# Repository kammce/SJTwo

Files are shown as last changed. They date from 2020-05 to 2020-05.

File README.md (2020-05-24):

# SJTwo

Open source development board for the LPC4078 microcontroller with buttons,
leds, sensors and display, used for educational purposes

## Source Files

I've made the DipTrace source files available so that you can download them,
inspect them, modify them, do whatever you want with them. They can be found in
the `diptrace/` directory. The root of the directory has the current Rev F
version of the board. All older versions can be found in the `diptrace/archives`
folder.

There is also a Segger JTAG Mini to SJTwo adapter in there as well, if you don't
want to connect header pins.

Also included are the `archives` datasheets, 3D models for the Diptrace 3D
renderer, old BOMs and the old gerbers.

Logos, images, datasheets, drawings and 3D models are owned by their respective
owners.

Forgive me for DipTrace as the files cannot be exported or converted to any
other platform, thus locking people into that ecosystem. I'd recommend EasyEDA
as an a free alternative. Fantastic web application that gets better everyday.
And if have the cash to pay for Altium, I'd recommend that.

## Ordering PCBs and BOM

Please go to this link on kitspace.org (adding link soon) to order a PCB and the
BOM.

## Developing software for the board
Go to [SJSU-Dev2](https://github.com/kammce/SJSU-Dev2/) to download the software
development kit for this board. The development platform also enables the
development of other boards and microcontrollers as well.

### Factory Testing board

A `.hex` file can be generated for the board by building the
[factory test demo](https://github.com/kammce/SJSU-Dev2/tree/master/demos/sjtwo/factory_test).

This binary can be loaded onto each chip before it is soldered onto the board.
And once the board is finished, power can be supplied to the board, and the 4
LEDs above the buttons will turn on when the test is finished. Should only take
a few seconds to complete. Serial output detailing the process can also be seen
via a serial terminal like Putty or minicom over a USB micro cable.

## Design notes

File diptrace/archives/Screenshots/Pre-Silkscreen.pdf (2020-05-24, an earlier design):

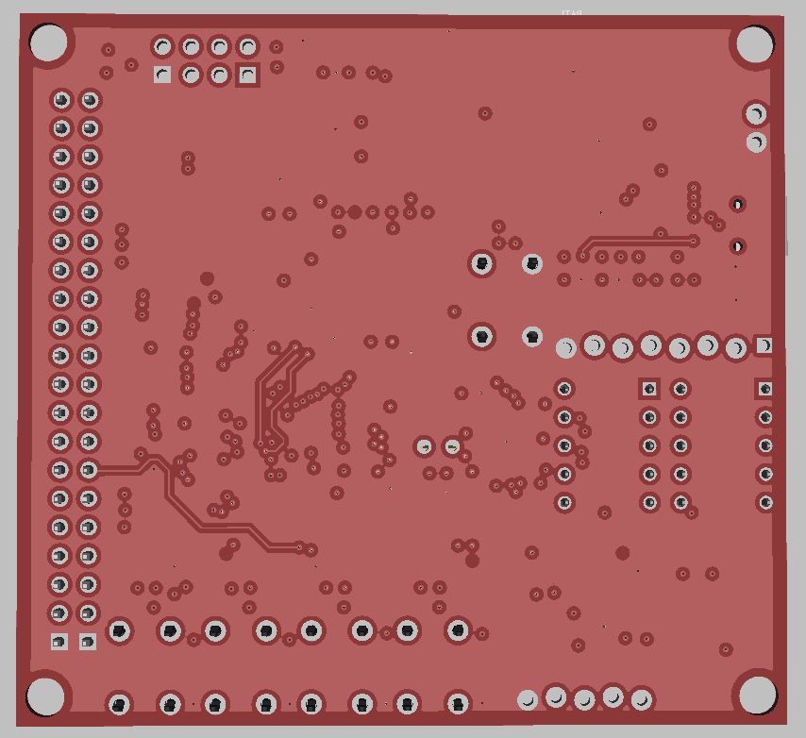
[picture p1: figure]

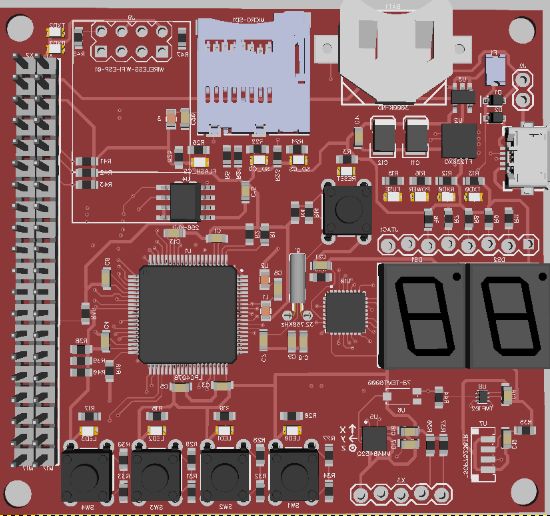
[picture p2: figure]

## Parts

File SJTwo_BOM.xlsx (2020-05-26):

References | Quantity | Description | Manufacturer | MPN | LCSC | Mouser | BuyDisplays | Stuff | Unit Cost @ 250 | Total Cost | Pins/Pads | Final Price
BAT1 | 1 | 12mm battery holder | Harwin | S8201-46R |  | 855-S8201-46R (https://www.mouser.com/ProductDetail/Harwin/S8201-46R/?qs=sGAEpiMZZMtT9MhkajLHrq0s4nToQPXS9pUF0UgGLqQ%3D) |  |  | $0.430000 | $0.430000 | 3 | $0.430000
C1, C5, C7, C8, C9, C10, C11, C13, C14, C21, C22, C23, C24, C25, C26, C27 | 16 | 100nF -20%,+80% 16V Y5V 0603 MLCC | Walsin Tech Corp | 0603F104Z160CT | C387984 (https://lcsc.com/product-detail/Multilayer-Ceramic-Capacitors-MLCC-SMD-SMT_Walsin-Tech-Corp-0603F104Z160CT_C387984.html) |  |  |  | $0.002561 | $0.040976 | 2 | $0.040976
C2, C3, C4, C6 | 4 | 18pF 5% 50V C0G 0603 MLCC | Samsung Electro-Mechanics | CL10C180JB8NNNC | C1647 (https://lcsc.com/product-detail/Multilayer-Ceramic-Capacitors-MLCC-SMD-SMT_SAMSUNG_CL10C180JB8NNNC_18pF-180-5-50V_C1647.html) |  |  |  | $0.004417 | $0.017668 | 2 | $0.017668
C12, C19, C20 | 3 | 2.2uF 10% 16V X5R 0603 MLCC | CCTC | TCC0603X5R225K160CT | C380320 (https://lcsc.com/product-detail/New-Arrivals_CCTC-TCC0603X5R225K160CT_C380320.html) |  |  |  | $0.006306 | $0.018918 | 2 | $0.018918
C15, C16 | 2 | 10uF 10% 10V X5R 0805 MLCC | Samsung Electro-Mechanics | CL21A106KPFNNNE | C17024 (https://lcsc.com/product-detail/Multilayer-Ceramic-Capacitors-MLCC-SMD-SMT_SAMSUNG_CL21A106KPFNNNE_10uF-106-10-10V_C17024.html) |  |  |  | $0.012473 | $0.024946 | 2 | $0.024946
C17, C18 | 2 | 1uF 5% 16V X5R 0603 MLCC | Walsin Tech Corp | 0603X105J160CT | C458913 (https://lcsc.com/product-detail/Multilayer-Ceramic-Capacitors-MLCC-SMD-SMT_Walsin-Tech-Corp-0603X105J160CT_C458913.html) |  |  |  | $0.017553 | $0.035106 | 2 | $0.035106
D1, D2 | 2 | 10V 3A 370mV @ 1A SOD-323-2 Schottky Barrier Diodes | Infineon Technologies | BAT60AE6327HTSA1 |  | 726-BAT60AE6327HTSA1 (https://www.mouser.com/ProductDetail/Infineon-Technologies/BAT60AE6327HTSA1?qs=OwbwYO03UsIW3Y2lCXbs8Q%3D%3D) |  |  | $0.144000 | $0.288000 | 2 | $0.288000
F1 | 1 | 30V 500mA 1206 PTC Resettable Fuses | TECHFUSE | nSMD025-30V | C70070 (https://lcsc.com/product-detail/Surface-Mount-Fuses_0-25A-30V-Self-healing-fuse_C70070.html) |  |  |  | $0.038757 | $0.038757 | 2 | $0.038757
J1 | 1 | Pin Header Male Pin 2.54mm 2x1 Through Hole | JST Sales America | RE-H022TD-1190(LF)(SN) | C160332 (https://lcsc.com/product-detail/Pin-Header-Female-Header_JST-Sales-America_RE-H022TD-1190-LF-SN_JST-Sales-America-RE-H022TD-1190-LF-SN_C160332.html) |  |  |  | $0.052529 | $0.052529 | 2 | $0.052529
J2 | 1 | 10118193-0001LF | Amphenol FCI | 10118193-0001LF | C132562 (https://lcsc.com/product-detail/Audio-Video-Connectors_Amphenol-ICC-10118193-0001LF_C132562.html) |  |  |  | $0.182955 | $0.182955 | 9 | $0.182955
J3 | 1 | Mirco SD Card Socket | Molex | 503182-0852 |  | 538-503182-1852 (https://www.mouser.com/ProductDetail/Molex/503182-1852/?qs=sGAEpiMZZMuJakaoiLiBppKNOqzXwmgw2eKnQVj7yHw%3D) |  |  | $1.560000 | $1.560000 | 11 | $1.560000
J4 | 1 | Pin Header Male Pin 2.54mm 8x1 Through Hole | Ckmtw | C124381 | C124381 (https://lcsc.com/product-detail/Pin-Header-Female-Header_Ckmtw-Shenzhen-Cankemeng-C124381_C124381.html) |  |  |  | $0.032082 | $0.032082 | 8 | $0.032082
J5, J6 | 2 | Pin Header Male Pin 2.54mm 20x1 Through Hole | Ckmtw | C124374 | C124374 (https://lcsc.com/product-detail/Pin-Header-Female-Header_Ckmtw-Shenzhen-Cankemeng-C124374_C124374.html) |  |  |  | $0.058586 | $0.117172 | 20 | $0.117172
L1, L2 | 2 | 0805 Ferrite Beads | TDK | MMZ2012Y300BTD25 | C501999 (https://lcsc.com/product-detail/Ferrite-Beads_TDK-MMZ2012Y300BTD25_C501999.html) |  |  |  | $0.034855 | $0.069710 | 2 | $0.069710
LED0, LED1, LED2, LED3, LED6 | 5 | Red 619~625nm 0603 Light Emitting Diodes | ARKLED | D-060306R1/SS2/L | C118330 (https://lcsc.com/product-detail/Light-Emitting-Diodes-LED_ARKLED-Wuxi-ARK-Tech-Elec-D-060306R1-SS2-L_C118330.html) |  |  |  | $0.010826 | $0.054130 | 2 | $0.054130
LED4, LED5, LED10, LED11, LED12, LED13, LED14 | 7 | Yellow 587~595nm 0603 Light Emitting Diodes | EKINGLUX | E6C0603UYAC1UDA | C375445 (https://lcsc.com/product-detail/Light-Emitting-Diodes-LED_EKINGLUX-E6C0603UYAC1UDA_C375445.html) |  |  |  | $0.013850 | $0.096950 | 2 | $0.096950
LED7, LED8 | 2 | Green 520~535nm 0603 Light Emitting Diodes | Orient | ORH-G36G | C205443 (https://lcsc.com/product-detail/Light-Emitting-Diodes-LED_0603-green_C205443.html) |  |  |  | $0.008752 | $0.017504 | 2 | $0.017504
R1, R3, R4, R6, R9, R19, R21, R33, R34, R35 | 10 | 10K 5% 1/10W 0603 Chip Resistor | FH | RS-03K103JT | C73809 (https://lcsc.com/product-detail/Chip-Resistor-Surface-Mount_FH-Guangdong-Fenghua-Advanced-Tech-RS-03K103JT_C73809.html) |  |  |  | $0.001409 | $0.014090 | 2 | $0.014090
R2, R5, R7, R8, R10, R13, R14, R15, R16, R17, R18, R20, R22, R23, R25, R26, R27, R30, R31 | 19 | 1K 5% 1/10W 0603 Chip Resistor | Uni-royal | 0603WAJ0102T5E | C25585 (https://lcsc.com/product-detail/Chip-Resistor-Surface-Mount_UNI-ROYAL-Uniroyal-Elec-0603WAJ0102T5E_C25585.html) |  |  |  | $0.000910 | $0.017290 | 2 | $0.017290
R11, R12 | 2 | 100 5% 1/10W 0603 Chip Resistor | Walsin Tech Corp | WR06X101JTL | C163845 (https://lcsc.com/product-detail/Chip-Resistor-Surface-Mount_Walsin-Tech-Corp-WR06X101JTL_C163845.html) |  |  |  | $0.000874 | $0.001748 | 2 | $0.001748
R24 | 1 | 402K 1% 1/10W 0603 Chip Resistor | RALEC | RTT034023FTP | C103619 (https://lcsc.com/product-detail/Chip-Resistor-Surface-Mount_402KR-4023-1_C103619.html) |  |  |  | $0.001485 | $0.001485 | 2 | $0.001485
R28, R29 | 2 | 4.7K 5% 1/10W 0603 Chip Resistor | FH | RS-03K472JT | C88615 (https://lcsc.com/product-detail/Chip-Resistor-Surface-Mount_FH-Guangdong-Fenghua-Advanced-Tech-RS-03K472JT_C88615.html) |  |  |  | $0.001409 | $0.002818 | 2 | $0.002818
R32 | 1 | 22 5% 1/10W 0603 Chip Resistor | FH | RS-03K220JT | C96423 (https://lcsc.com/product-detail/Chip-Resistor-Surface-Mount_FH-Guangdong-Fenghua-Advanced-Tech-RS-03K220JT_C96423.html) |  |  |  | $0.000921 | $0.000921 | 2 | $0.000921
RESET1, SW0, SW1, SW2, SW3 | 5 | SPST-NO Top Actuated Standard 6*6*5mm Tactile Switches | SOFNG | TS-1102-5016 | C111609 (https://lcsc.com/product-detail/Tactile-Switches_SOFNG-TS-1102-5016_C111609.html) |  |  |  | $0.029484 | $0.147420 | 4 | $0.147420
U1 | 1 | LPC4078 | NXP-Philips | LPC4078FBD80,551 |  | 771-LPC4078FBD80551 (https://www.mouser.com/ProductDetail/NXP-Semiconductors/LPC4078FBD80551/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) |  |  | $7.620000 | $7.620000 | 80 | $7.620000
U2 | 1 | Fixed 6V 3.3V 600mA SOT-25 LDO | Diodes Incorporated | AP2112K-3.3TRG1 | C51118 (https://lcsc.com/product-detail/Low-Dropout-Regulators-LDO_DIODES_AP2112K-3-3TRG1_AP2112K-3-3TRG1_C51118.html) |  |  |  | $0.0878020 | $0.0878020 | 5 | $0.087802
U3 | 1 | CP2102n | Silicon Lab | CP2102N-A01-GQFN28R |  | 634-CP2102NA01GQFN20 (https://www.mouser.com/productdetail/silicon-labs/cp2102n-a01-gqfn20) |  |  | $1.2300000 | $1.2300000 | 29 | $1.230000
U4 | 1 | 0.96" OLED Displays Modules | Shenzhen Allvision Tech | QG-2864KSWEG01 | C85007 (https://lcsc.com/product-detail/OLED-Displays-Modules_0-96-128x64-150cd-m2-Typ-at-9V_C85007.html) |  | ER-OLED0.96-1W (https://www.buydisplay.com/datasheet-128x64-oled-module-spi-0-96-inch-graphic-displays-white-on-black) |  | $2.3600000 | $2.3600000 | 30 | $2.360000
U5 | 1 | Si7060 temperature sensor | Silicon Labs | SI7060-B-02-IVR |  | 634-SI7060-B-02-IVR (https://www.mouser.com/ProductDetail/Silicon-Labs/SI7060-B-02-IVR?qs=r5DSvlrkXmLx4OghvUfaHg%3D%3D) |  |  | $0.3400000 | $0.3400000 | 5 | $0.340000
U6 | 1 | MMA8452QR1 Acclerometer | NXP Semicon | MMA8452QR1 | C11360 (https://lcsc.com/product-detail/Motion-Sensors-Accelerometers_NXP-Semicon-MMA8452QR1_C11360.html) |  |  |  | $0.8194770 | $0.8194770 | 16 | $0.819477
U7 | 1 | ESP-01S | Ai-Thinker | ESP-01S |  |  |  | DNS | $0.0000000 | $0.0000000 | 8 | $0.000000
U8 | 1 | AT25SF041 Flash Memory | Atmel | AT25SF041-SSHD-T | C161759 (https://lcsc.com/product-detail/FLASH_Adesto-Technologies_AT25SF041-SSHD-T_Adesto-Technologies-AT25SF041-SSHD-T_C161759.html) |  |  |  | $0.1718820 | $0.1718820 | 8 | $0.171882
U9 | 1 | APDS-9960 Gesture sensor | Avago | APDS-9960 |  | 630-APDS-9960 (https://www.mouser.com/ProductDetail/Broadcom-Limited/APDS-9960/?qs=9j6qqDjiC68hPiaH59tKpQ%3D%3D) |  |  | $1.4000000 | $1.4000000 | 8 | $1.400000
Y1 | 1 | 32.768KHz Crystal | IQD | XNMCZLNDED-32.768KHZ | C124333 (https://lcsc.com/product-detail/SMD-Crystal-Resonators_TAITIEN-Elec-XNMCZLNDED-32-768KHZ_C124333.html) |  |  |  | $0.1611750 | $0.1611750 | 4 | $0.161175
Y2 | 1 | 12MHz Crystal | Yangxing Tech | X49SD12MSD2SC | C16369 (https://lcsc.com/product-detail/DIP-Crystal-Resonators_Yangxing-Tech-X49SD12MSD2SC_C16369.html) |  |  |  | $0.0432970 | $0.0432970 | 2 | $0.043297
Totals | 104 |  |  |  |  |  |  |  |  | $17.496808 | 286 | $17.496808

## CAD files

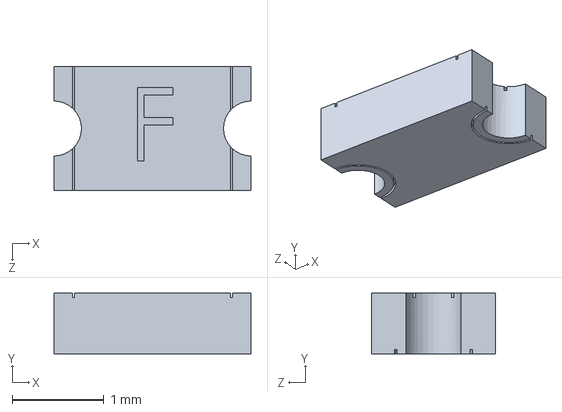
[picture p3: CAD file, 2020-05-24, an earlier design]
diptrace/archives/3D-Models/Part2.SLDPRT
2.15 x 0.665 x 1.35 mm

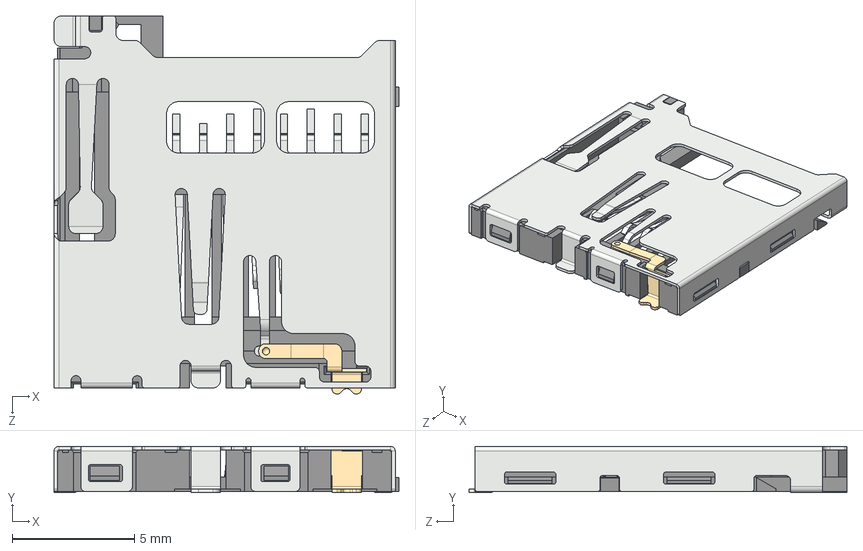
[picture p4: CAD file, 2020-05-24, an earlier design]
diptrace/archives/3D-Models/micro SD Card Slot.step
14.1 x 1.90 x 15.5 mm
microSD_Body
microSD_Cover
microSD_Card_Detect
microSD_Pin_11.15 x 5
microSD_Pin_11.35 x 2
microSD_Pin_10.75

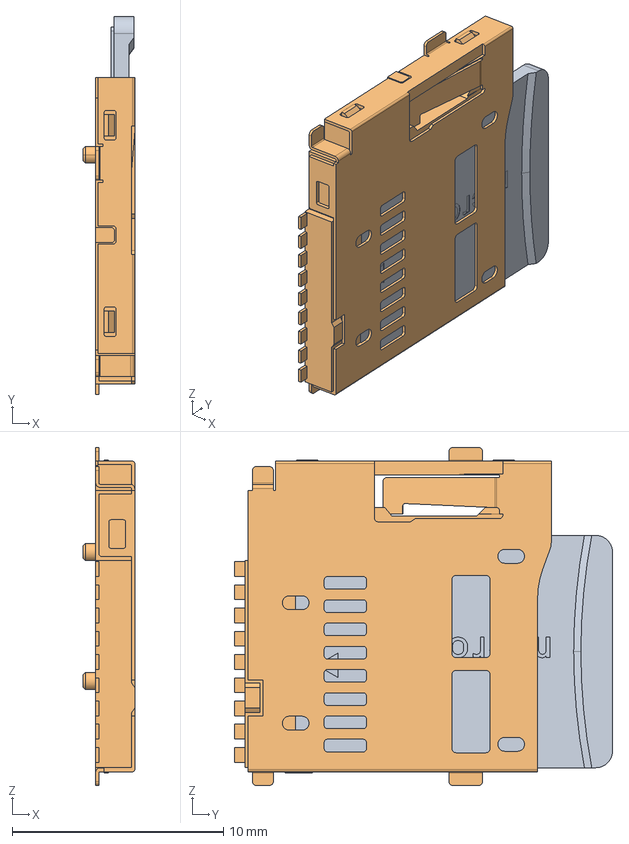
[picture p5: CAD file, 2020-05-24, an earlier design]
diptrace/archives/3D-Models/micro sd.stp
2.44 x 17.9 x 16.0 mm
P1
sd
slot

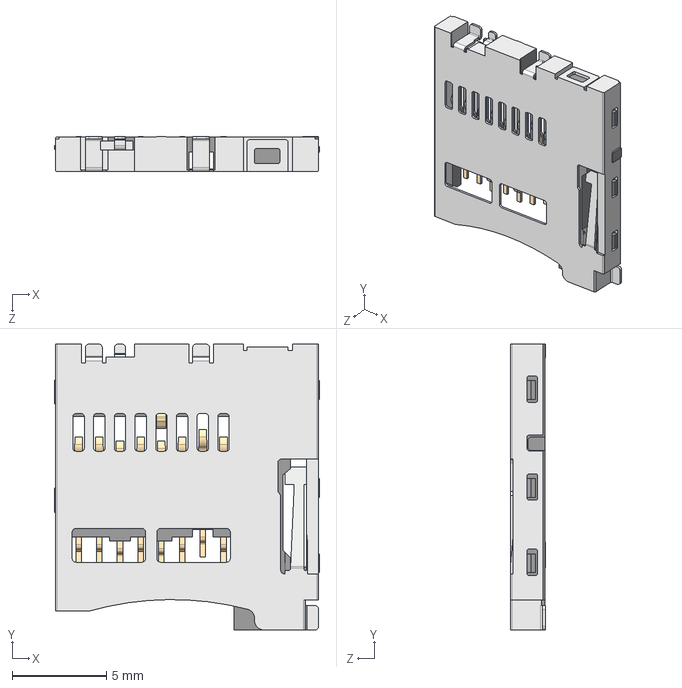
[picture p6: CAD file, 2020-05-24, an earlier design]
diptrace/archives/3D-Models/473521001_microSD.stp
14.1 x 15.2 x 1.88 mm

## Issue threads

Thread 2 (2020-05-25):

Create SJTwo Rev F

kammce, 2020-05-25:
Along with a report of a mislabelled pin, the BOM was optimized after Rev E and a few elements have to be updated.

- [ ] Swap out SD card socket with economic socket
- [ ] Rename SPI flash to reflect the cheaper 8MB flash being used
- [ ] Investigate and fix report of a mislabeled pin

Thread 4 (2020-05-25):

Get kitspace to detect gerbers as 4 layer

kammce, 2020-05-25:

kasbah, 2020-09-25:
The drill files are not being picked up either. We use a package called [whats-that-gerber](https://github.com/tracespace/tracespace/tree/master/packages/whats-that-gerber) where we did implement DipTrace support. Kitspace is not using the latest version of that package though, need to upgrade and see if it's still an issue.

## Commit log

2020-05-24 Add Initial Gerbers and bill of materials
    Note the BOM is for Rev F and gerbers are for Rev E
    [BoardOutline.gbr, Bottom.gbr, BottomAssy.gbr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]
2020-05-24 Correct bom filename typo in yaml
2020-05-24 Fixup on yaml files
    - Renamed bill_of_materials.tsv to bom.csv
    - Moved from tsv to csv (thought the file needed to be tsv)
    [bill_of_materials.tsv, bom.csv]
2020-05-24 Adding DipTrace files
    [473521001_microSD.stp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]
2020-05-24 Specifying gerbers location in the kitnit.yaml
    Migrating Gerbers in archives to Old-Gerbers in order to keep kitspace
    from getting confused.
    [BoardOutline.gbr, Bottom.gbr, BottomAssy.gbr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]
2020-05-24 Removed "buydisplays" column from BOM
    [bom.csv]
2020-05-24 Using 1-click-bom to complete the BOM
    [bom.csv]
2020-05-25 Change SD Card slot + reduced fields from bom
    [bom.csv]
2020-05-25 Convert csv to tsv
    TSV is easier to copy directly from 1 click bom and excel/google
    spreadsheets to text files.
    Changed many of the items in the bom to use mouser rather than lscs.
    [bom.csv, bom.tsv]
2020-05-26 Correcting part for expansion port
    [bom.tsv]
2020-05-26 Adding various generated files
    - Added BOM excel sheet
    - Added pick and place files
    - Added SJTwo.zip with gerbers, pick and place and bom.
    [SJTwo-RevE-pick-and-place.csv, SJTwo-RevE-pick-and-place.xlsx, SJTwo_BOM.xlsx]
